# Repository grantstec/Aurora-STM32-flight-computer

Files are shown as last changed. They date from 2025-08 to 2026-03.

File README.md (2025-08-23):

# Aurora-STM32-flight-computer

## TO-DO
1. Finalize Parts List
2. Begin Schematic
3. Import OSH park pcb settings into KiCAD
4. Footprint demensions
5. Assemble footprint/layout
6. Traces
7. 3d Model?

## Resources
OSH park pcb setup link: https://github.com/grantstec/Aurora-STM32-flight-computer.git

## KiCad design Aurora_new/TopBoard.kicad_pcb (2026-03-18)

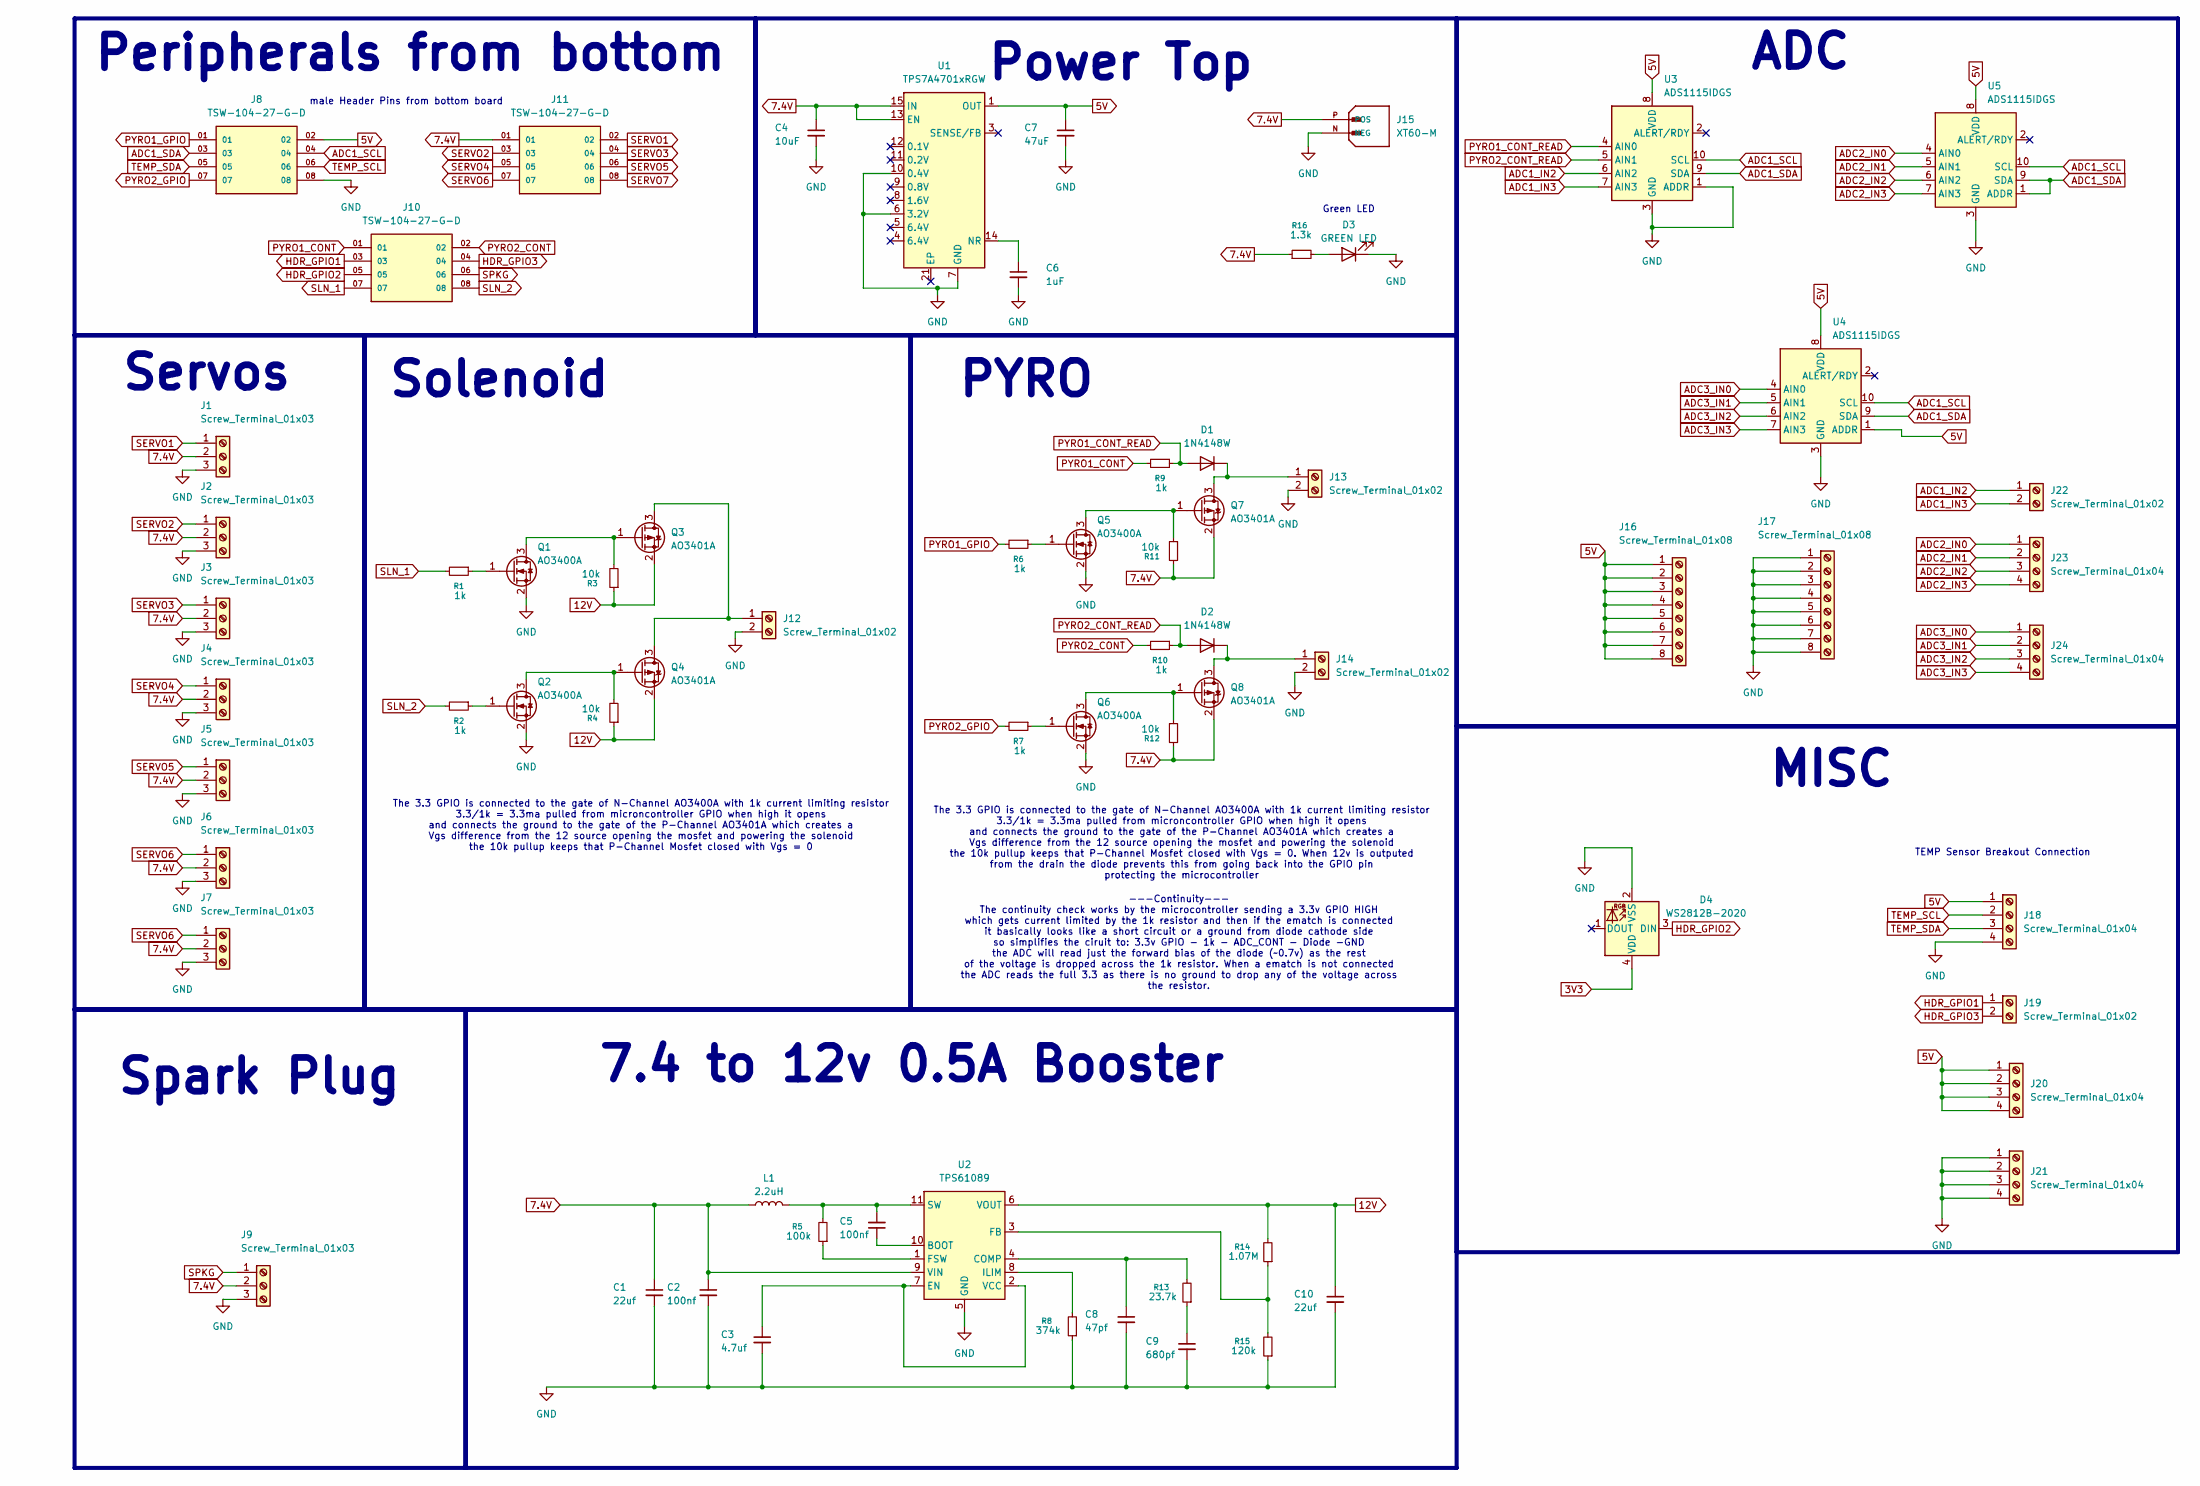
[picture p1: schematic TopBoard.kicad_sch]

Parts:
C1, C10: 22uf; C_0805_2012Metric
C2, C5: 100nf; C_0805_2012Metric
C3: 4.7uf; C_0805_2012Metric
C4: 10uF; C_0805_2012Metric
C6: 1uF; C_0805_2012Metric
C7: 47uF; C_0805_2012Metric
C8: 47pf; C_0805_2012Metric
C9: 680pf; C_0805_2012Metric
D1, D2: 1N4148W; D_SOD-123
D3: GREEN LED; LED_Cree-PLCC4_5x5mm_CW
D4: WS2812B-2020; LED_WS2812B-2020_PLCC4_2.0x2.0mm
J1, J2, J3, J4, J5, J6, J7, J9: Screw_Terminal_01x03; PHOENIX_1935174
J8, J10, J11: TSW-104-27-G-D; SAMTEC_TSW-104-27-G-D; PARTREV R
J12, J13, J14, J19, J22: Screw_Terminal_01x02; CONN_1729128_PXC
J15: XT60-M; AMASS_XT60-M; PARTREV V1.2
J16, J17: Screw_Terminal_01x08; CONN_1715789_PXC
J18, J20, J21, J23, J24: Screw_Terminal_01x04; CONN_1715747_PXC
L1: 2.2uH; L_0805_2012Metric
Q1, Q2, Q5, Q6: AO3400A; SOT-23
Q3, Q4, Q7, Q8: AO3401A; SOT-23
R1, R2, R6, R7, R9, R10: 1k; R_0805_2012Metric
R3, R4, R11, R12: 10k; R_0805_2012Metric
R5: 100k; R_0805_2012Metric
R8: 374k; R_0805_2012Metric
R13: 23.7k; R_0805_2012Metric
R14: 1.07M; R_0805_2012Metric
R15: 120k; R_0805_2012Metric
R16: 1.3k; R_0805_2012Metric
U1: TPS7A4701xRGW; Texas_RGW0020A_VQFN-20-1EP_5x5mm_P0.65mm_EP3.15x3.15mm
U2: TPS61089; Texas_VQFN-RNR0011A-11
U3, U4, U5: ADS1115IDGS; TSSOP-10_3x3mm_P0.5mm

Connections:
3V3: D4.4 (VDD)
5V: C7.1, J8.02, J16.1, J16.2, J16.3, J16.4, J16.5, J16.6, J16.7, J16.8, J18.1, J20.1, J20.2, J20.3, J20.4, U1.1 (OUT), U1.20 (OUT), U3.8 (VDD), U4.1 (ADDR), U4.8 (VDD), U5.8 (VDD)
7.4V: C1.1, C2.1, C4.1, J1.2, J2.2, J3.2, J4.2, J5.2, J6.2, J7.2, J9.2, J11.01, J15.P (POS), L1.1, Q7.2 (S), Q8.2 (S), R11.1, R12.1, R16.1, U1.13 (EN), U1.15 (IN), U1.16 (IN), U2.9 (VIN)
12V: C10.1, Q3.2 (S), Q4.2 (S), R3.1, R4.1, R14.2, U2.6 (VOUT)
ADC1_IN2: J22.1, U3.6 (AIN2)
ADC1_IN3: J22.2, U3.7 (AIN3)
ADC1_SCL: J8.04, U3.10 (SCL), U4.10 (SCL), U5.10 (SCL)
ADC1_SDA: J8.03, U3.9 (SDA), U4.9 (SDA), U5.1 (ADDR), U5.9 (SDA)
ADC2_IN0: J23.1, U5.4 (AIN0)
ADC2_IN1: J23.2, U5.5 (AIN1)
ADC2_IN2: J23.3, U5.6 (AIN2)
ADC2_IN3: J23.4, U5.7 (AIN3)
ADC3_IN0: J24.1, U4.4 (AIN0)
ADC3_IN1: J24.2, U4.5 (AIN1)
ADC3_IN2: J24.3, U4.6 (AIN2)
ADC3_IN3: J24.4, U4.7 (AIN3)
GND: C1.2, C2.2, C3.2, C4.2, C6.2, C7.2, C8.2, C9.2, C10.2, D3.1 (K), D4.2 (VSS), J1.3, J2.3, J3.3, J4.3, J5.3, J6.3, J7.3, J8.08, J9.3, J12.2, J13.2, J14.2, J15.N (NEG), J17.1, J17.2, J17.3, J17.4, J17.5, J17.6, J17.7, J17.8, J18.4, J21.1, J21.2, J21.3, J21.4, Q1.2 (S), Q2.2 (S), Q5.2 (S), Q6.2 (S), R8.1, R15.1, U1.6 (3.2V), U1.7 (GND), U1.10 (0.4V), U2.5 (GND), U3.1 (ADDR), U3.3 (GND), U4.3 (GND), U5.3 (GND)
HDR_GPIO1: J10.03, J19.1
HDR_GPIO2: D4.3 (DIN), J10.05
HDR_GPIO3: J10.04, J19.2
unnamed: C9.1, R13.1
unnamed: D1.1 (K), J13.1, Q7.3 (D)
unnamed: D2.1 (K), J14.1, Q8.3 (D)
unnamed: D3.2 (A), R16.2
unnamed: J12.1, Q3.3 (D), Q4.3 (D)
unnamed: Q1.3 (D), Q3.1 (G), R3.2
unnamed: Q1.1 (G), R1.1
unnamed: Q2.3 (D), Q4.1 (G), R4.2
unnamed: Q2.1 (G), R2.1
unnamed: Q5.3 (D), Q7.1 (G), R11.2
unnamed: Q5.1 (G), R6.1
unnamed: Q6.3 (D), Q8.1 (G), R12.2
unnamed: Q6.1 (G), R7.1
unnamed: C6.1, U1.14 (NR)
unnamed: C5.1, U2.10 (BOOT)
unnamed: C8.1, R13.2, U2.4 (COMP)
unnamed: C3.1, U2.2 (VCC), U2.7 (EN)
unnamed: R14.1, R15.2, U2.3 (FB)
unnamed: R5.1, U2.1 (FSW)
unnamed: R8.2, U2.8 (ILIM)
unnamed: C5.2, L1.2, R5.2, U2.11 (SW)
PYRO1_CONT: J10.01, R9.2
PYRO1_CONT_READ: D1.2 (A), R9.1, U3.4 (AIN0)
PYRO1_GPIO: J8.01, R6.2
PYRO2_CONT: J10.02, R10.2
PYRO2_CONT_READ: D2.2 (A), R10.1, U3.5 (AIN1)
PYRO2_GPIO: J8.07, R7.2
SERVO1: J1.1, J11.02
SERVO2: J2.1, J11.03
SERVO3: J3.1, J11.04
SERVO4: J4.1, J11.05
SERVO5: J5.1, J11.06
SERVO6: J6.1, J7.1, J11.07
SERVO7: J11.08
SLN_1: J10.07, R1.2
SLN_2: J10.08, R2.2
SPKG: J9.1, J10.06
TEMP_SCL: J8.06, J18.2
TEMP_SDA: J8.05, J18.3

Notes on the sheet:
ADC
Power Top
MISC
male Header Pins from bottom board
The 3.3 GPIO is connected to the gate of N-Channel AO3400A with 1k current limiting resistor 3.3/1k = 3.3ma pulled from microncontroller GPIO when high it opens and connects the ground to the gate of the P-Channel AO3401A which creates a Vgs difference from the 12 source opening the mosfet and powe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
Peripherals from bottom
PYRO
TEMP Sensor Breakout Connection
Spark Plug
The 3.3 GPIO is connected to the gate of N-Channel AO3400A with 1k current limiting resistor 3.3/1k = 3.3ma pulled from microncontroller GPIO when high it opens and connects the ground to the gate of the P-Channel AO3401A which creates a Vgs difference from the 12 source opening the mosfet and powe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
---Continuity--- The continuity check works by the microcontroller sending a 3.3v GPIO HIGH which gets current limited by the 1k resistor and then if the ematch is connected it basically looks like a short circuit or a ground from diode cathode side so simplifies the ciruit to: 3.3v GPIO - 1k - ADC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
Green LED
7.4 to 12v 0.5A Booster
Solenoid
Servos

Board: 2 copper layers, 68 parts (0 on the bottom side), 57 nets, no tracks yet.

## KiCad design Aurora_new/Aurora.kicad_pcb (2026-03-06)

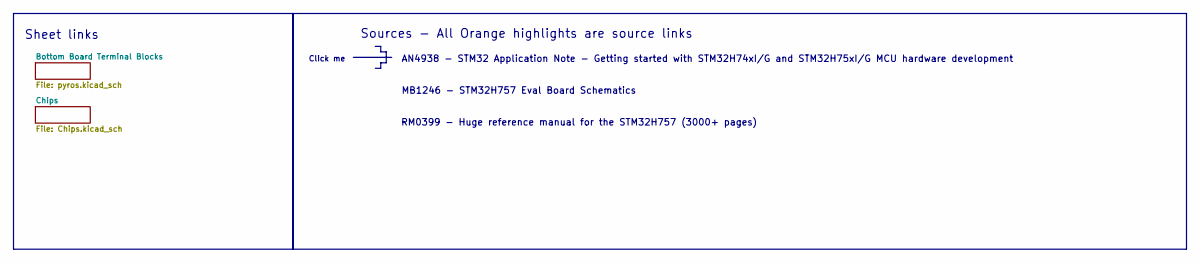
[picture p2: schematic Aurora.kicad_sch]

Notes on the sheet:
RM0399 - Huge reference manual for the STM32H757 (3000+ pages)
AN4938 - STM32 Application Note - Getting started with STM32H74xI/G and STM32H75xI/G MCU hardware development
MB1246 - STM32H757 Eval Board Schematics
Sheet links
Sources - All Orange highlights are source links
Click me

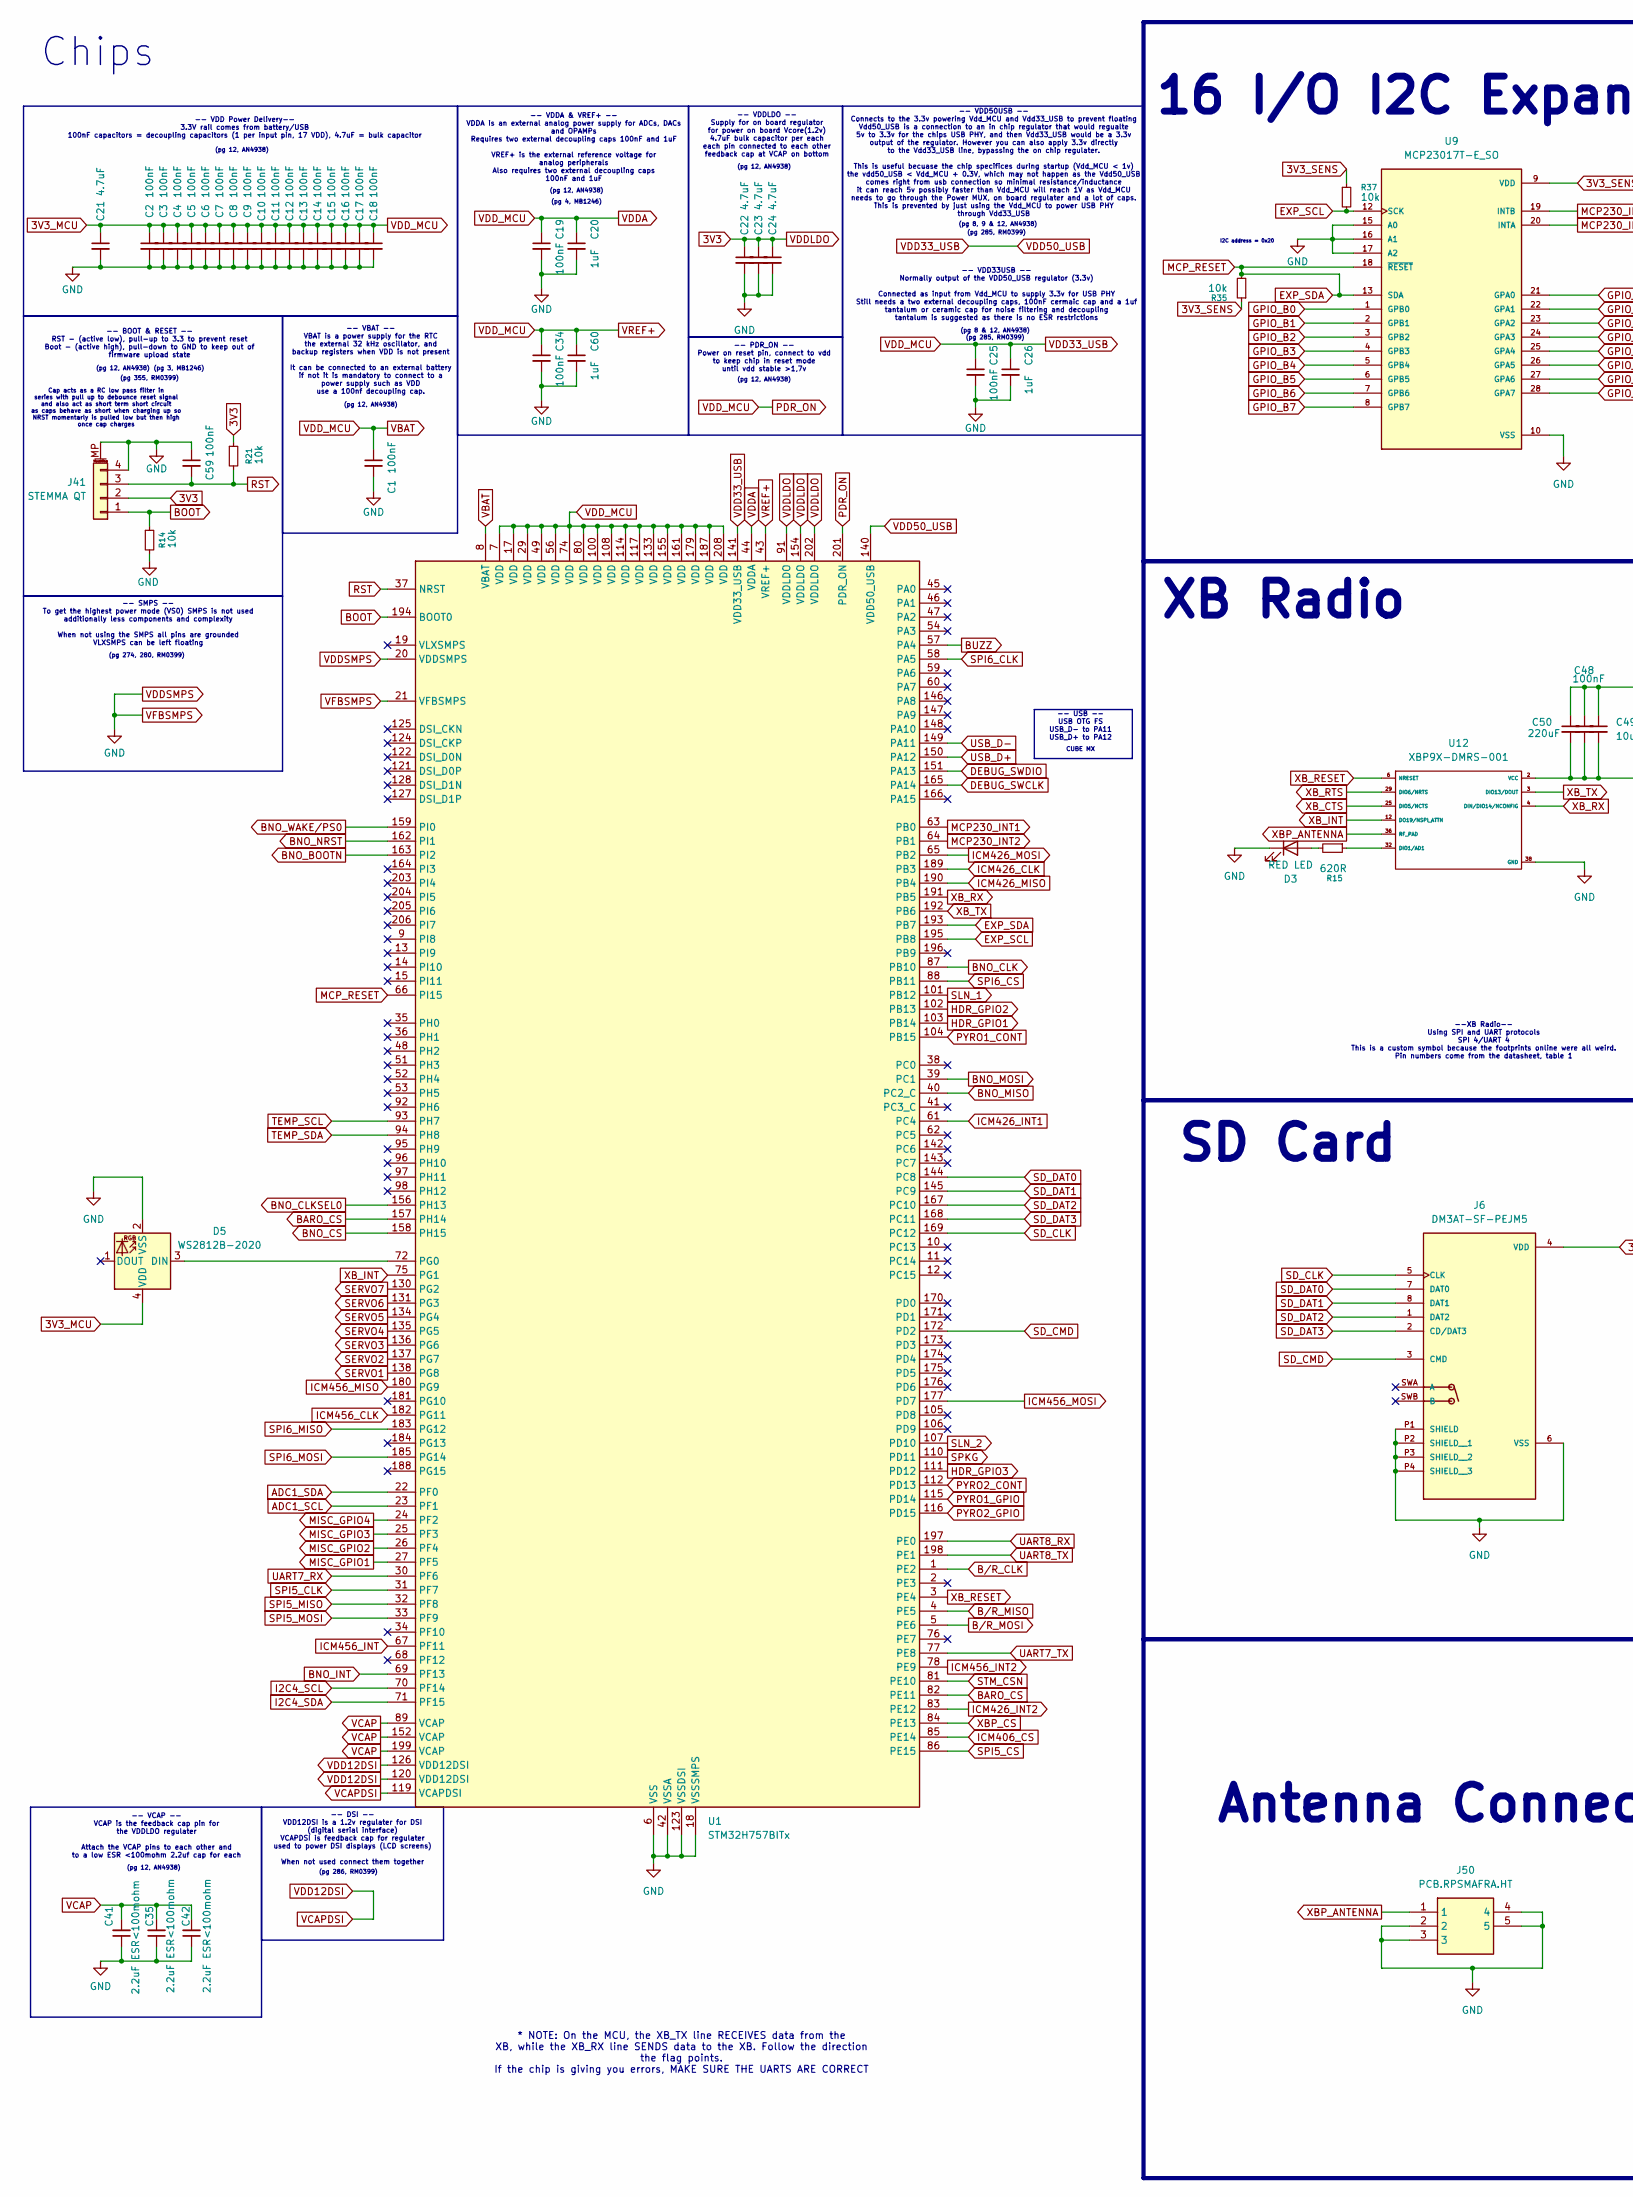
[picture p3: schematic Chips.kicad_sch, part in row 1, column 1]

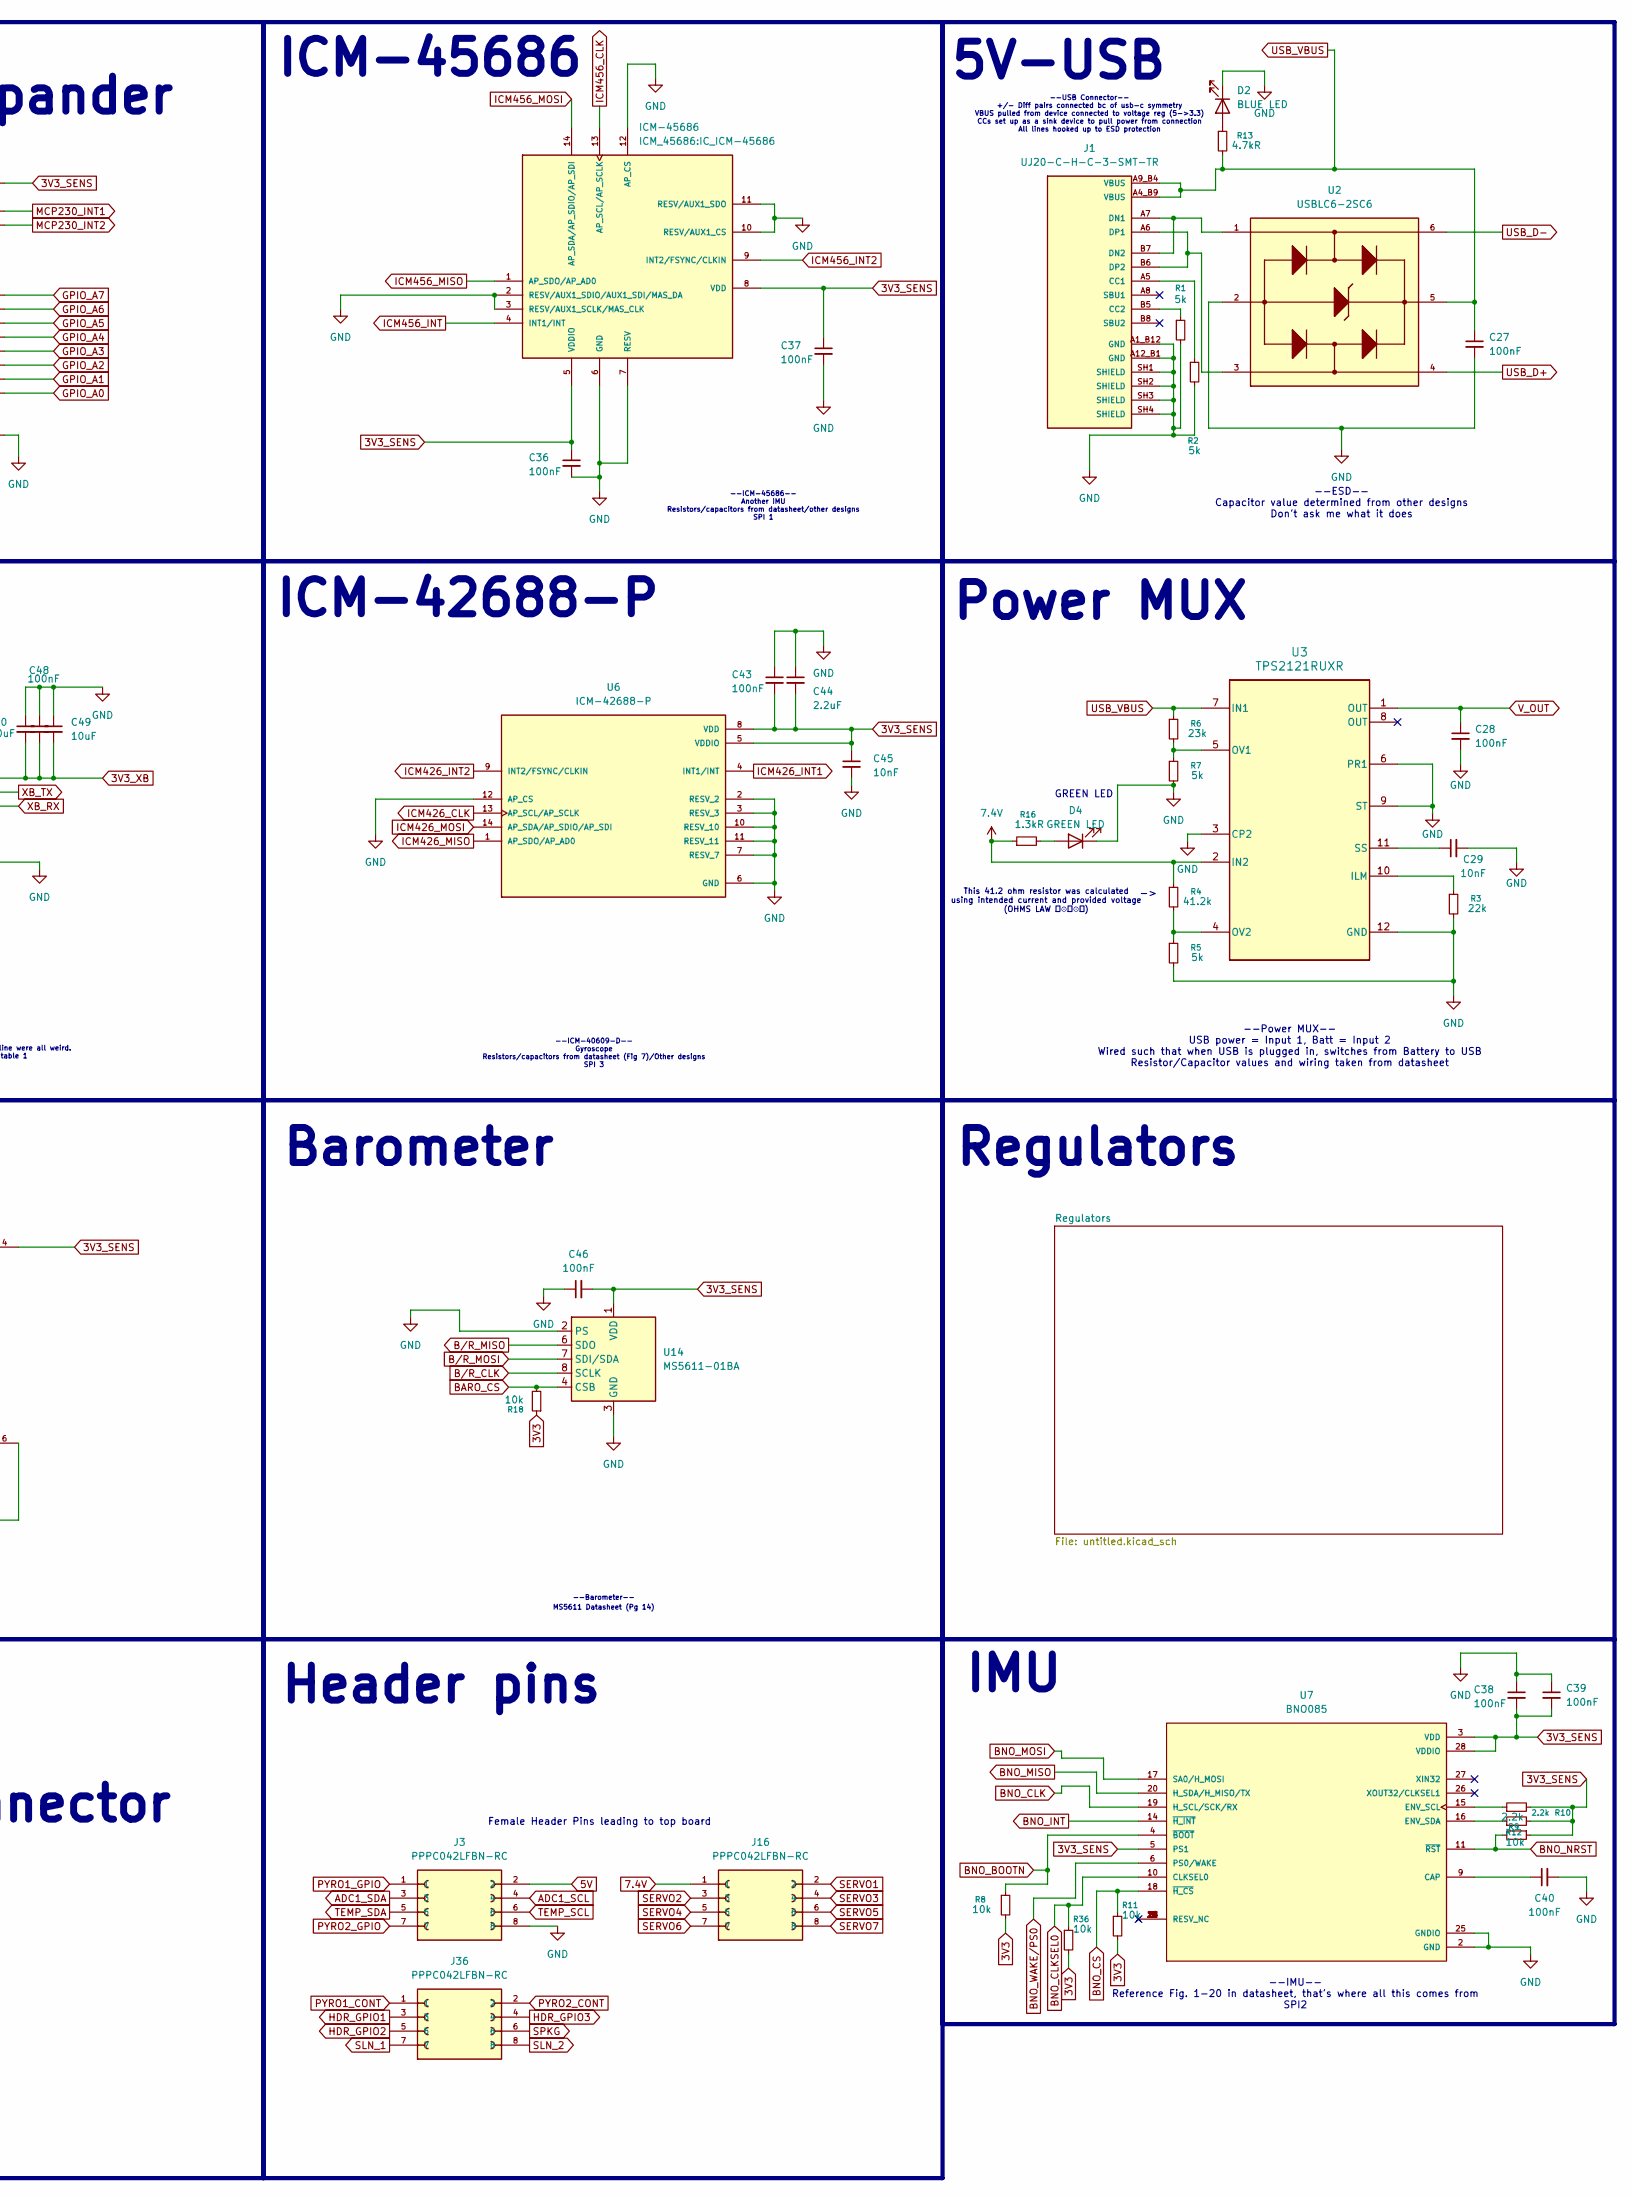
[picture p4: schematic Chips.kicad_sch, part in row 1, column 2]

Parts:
C1, C2, C3, C4, C5, C6, C7, C8, C9, C10, C11, C12, C13, C14, C15, C16, C17, C18, C19, C25, C27, C28, C34, C36, C37, C38, C39, C40, C43, C46, C48, C59: 100nF; C_0805_2012Metric
C20, C26, C60: 1uF; C_0805_2012Metric
C21, C22, C23, C24: 4.7uF; C_0805_2012Metric
C29, C45: 10nF; C_0805_2012Metric
C35, C41, C42: 2.2uF ESR<100mohm; C_0805_2012Metric
C44: 2.2uF; C_0805_2012Metric
C49: 10uF; C_0805_2012Metric
C50: 220uF; C_1206_3216Metric
D2: BLUE LED; LED_Cree-PLCC4_5x5mm_CW
D3: RED LED; LED_Cree-PLCC4_5x5mm_CW
D4: GREEN LED; LED_Cree-PLCC4_5x5mm_CW
D5: WS2812B-2020; LED_WS2812B-2020_PLCC4_2.0x2.0mm
J1: UJ20-C-H-C-3-SMT-TR; CUI_UJ20-C-H-C-3-SMT-TR; PARTREV 1.0
J3, J16, J36: PPPC042LFBN-RC; SULLINS_PPPC042LFBN-RC; PARTREV L
J6: DM3AT-SF-PEJM5; HRS_DM3AT-SF-PEJM5; PARTREV 20200913
J41: STEMMA QT; JST_SH_SM04B-SRSS-TB_1x04-1MP_P1.00mm_Horizontal
J50: PCB.RPSMAFRA.HT; PCBRPSMAFRAHT; Mouser Part Number 960-PCB.RPSMAFRA.HT
R1, R2, R5, R7: 5k; R_0805_2012Metric
R3: 22k; R_0805_2012Metric
R4: 41.2k; R_0805_2012Metric
R6: 23k; R_0805_2012Metric
R8, R11, R12, R14, R18, R21, R35, R36, R37: 10k; R_0805_2012Metric
R9, R10: 2.2k; R_0805_2012Metric
R13: 4.7kR; R_0805_2012Metric
R15: 620R; R_0805_2012Metric
R16: 1.3kR; R_0805_2012Metric
U1: STM32H757BITx; LQFP-208_28x28mm_P0.5mm
U2: USBLC6-2SC6; SOT95P280X145-6N
U3: TPS2121RUXR; RUX0012A
U5: ICM-45686; IC_ICM-45686; PARTREV 0.2
U6: ICM-42688-P; PQFN50P300X250X97-14N; PARTREV 1.2
U7: BNO085; IC_BNO085; PARTREV v1.17
U9: MCP23017T-E_SO; SOIC127P1030X265-28N
U12: XBP9X-DMRS-001; XCVR_XBP9X-DMUS-021
U14: MS5611-01BA; LGA-8_3x5mm_P1.25mm

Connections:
3V3: C22.1, C23.1, C24.1, J41.2, R8.2, R11.2, R18.1, R21.1, R36.2, U1.91 (VDDLDO), U1.154 (VDDLDO), U1.202 (VDDLDO); also elsewhere on the board
3V3_MCU: C1.1, C2.1, C3.1, C4.1, C5.1, C6.1, C7.1, C8.1, C9.1, C10.1, C11.1, C12.1, C13.1, C14.1, C15.1, C16.1, C17.1, C18.1, C19.1, C20.1, C21.1, C25.1, C26.1, C34.1, C60.1, D5.4 (VDD), U1.7 (VDD), U1.8 (VBAT), U1.17 (VDD), U1.29 (VDD), U1.43 (VREF+), U1.44 (VDDA), U1.49 (VDD), U1.56 (VDD), U1.74 (VDD), U1.80 (VDD), U1.100 (VDD), U1.108 (VDD), U1.114 (VDD), U1.117 (VDD), U1.133 (VDD), U1.140 (VDD50_USB), U1.141 (VDD33_USB), U1.155 (VDD), U1.161 (VDD), U1.179 (VDD), U1.187 (VDD), U1.201 (PDR_ON), U1.208 (VDD); also elsewhere on the board
3V3_SENS: C36.1, C37.1, C38.2, C39.2, C43.2, C44.2, C45.1, C46.2, J6.4 (VDD), R9.2, R10.2, R12.1, R35.1, R37.1, U5.5 (VDDIO), U5.8 (VDD), U6.5 (VDDIO), U6.8 (VDD), U7.3 (VDD), U7.5 (PS1), U7.28 (VDDIO), U9.9 (VDD), U14.1 (VDD); also elsewhere on the board
3V3_XB: C48.2, C49.2, C50.2, U12.2 (VCC); also elsewhere on the board
5V: J3.2
7.4V: J16.1, R4.1, R16.1, U3.2 (IN2)
ADC1_SCL: J3.4, U1.23 (PF1)
ADC1_SDA: J3.3, U1.22 (PF0)
BARO_CS: R18.2, U1.82 (PE11), U1.157 (PH14), U14.4 (CSB), U14.5 (CSB)
BNO_BOOTN: R8.1, U1.163 (PI2), U7.4 (~BOOT)
BNO_CLK: U1.87 (PB10), U7.19 (H_SCL/SCK/RX)
BNO_CLKSEL0: R36.1, U1.156 (PH13), U7.10 (CLKSEL0)
BNO_CS: R11.1, U1.158 (PH15), U7.18 (~H_CS)
BNO_INT: U1.69 (PF13), U7.14 (~H_INT)
BNO_MISO: U1.40 (PC2_C), U7.20 (H_SDA/H_MISO/TX)
BNO_MOSI: U1.39 (PC1), U7.17 (SA0/H_MOSI)
BNO_NRST: R12.2, U1.162 (PI1), U7.11 (~RST)
BNO_WAKE/PS0: U1.159 (PI0), U7.6 (PS0/WAKE)
BOOT: J41.1, R14.1, U1.194 (BOOT0)
BUZZ: U1.57 (PA4); also elsewhere on the board
B/R_CLK: U1.1 (PE2), U14.8 (SCLK)
B/R_MISO: U1.4 (PE5), U14.6 (SDO)
B/R_MOSI: U1.5 (PE6), U14.7 (SDI/SDA)
DEBUG_SWCLK: U1.165 (PA14); also elsewhere on the board
DEBUG_SWDIO: U1.151 (PA13); also elsewhere on the board
EXP_SCL: R37.2, U1.195 (PB8), U9.12 (SCK)
EXP_SDA: R35.2, U1.66 (PI15), U1.193 (PB7), U9.13 (SDA), U9.18 (~RESET)
GPIO_A0: U9.28 (GPA7); also elsewhere on the board
GPIO_A1: U9.27 (GPA6); also elsewhere on the board
GPIO_A2: U9.26 (GPA5); also elsewhere on the board
GPIO_A3: U9.25 (GPA4); also elsewhere on the board
GPIO_A4: U9.24 (GPA3); also elsewhere on the board
GPIO_A5: U9.23 (GPA2); also elsewhere on the board
GPIO_A6: U9.22 (GPA1); also elsewhere on the board
GPIO_A7: U9.21 (GPA0); also elsewhere on the board
GPIO_B0: U9.1 (GPB0); also elsewhere on the board
GPIO_B1: U9.2 (GPB1); also elsewhere on the board
GPIO_B2: U9.3 (GPB2); also elsewhere on the board
GPIO_B3: U9.4 (GPB3); also elsewhere on the board
GPIO_B4: U9.5 (GPB4); also elsewhere on the board
GPIO_B5: U9.6 (GPB5); also elsewhere on the board
GPIO_B6: U9.7 (GPB6); also elsewhere on the board
GPIO_B7: U9.8 (GPB7); also elsewhere on the board
HDR_GPIO1: J36.3, U1.103 (PB14)
HDR_GPIO2: J36.5, U1.102 (PB13)
HDR_GPIO3: J36.4, U1.111 (PD12)
I2C4_SCL: U1.70 (PF14); also elsewhere on the board
I2C4_SDA: U1.71 (PF15); also elsewhere on the board
ICM406_CS: U1.85 (PE14)
ICM426_CLK: U1.189 (PB3), U6.13 (AP_SCL/AP_SCLK)
ICM426_INT1: U1.61 (PC4), U6.4 (INT1/INT)
ICM426_INT2: U1.83 (PE12), U6.9 (INT2/FSYNC/CLKIN)
ICM426_MISO: U1.190 (PB4), U6.1 (AP_SDO/AP_AD0)
ICM426_MOSI: U1.65 (PB2), U6.14 (AP_SDA/AP_SDIO/AP_SDI)
ICM456_CLK: U1.182 (PG11), U5.13 (AP_SCL/AP_SCLK)
ICM456_INT: U1.67 (PF11), U5.4 (INT1/INT)
ICM456_INT2: U1.78 (PE9), U5.9 (INT2/FSYNC/CLKIN)
ICM456_MISO: U1.180 (PG9), U5.1 (AP_SDO/AP_AD0)
ICM456_MOSI: U1.177 (PD7), U5.14 (AP_SDA/AP_SDIO/AP_SDI)
MCP230_INT1: U1.63 (PB0), U9.19 (INTB)
MCP230_INT2: U1.64 (PB1), U9.20 (INTA)
MISC_GPIO1: U1.27 (PF5); also elsewhere on the board
MISC_GPIO2: U1.26 (PF4); also elsewhere on the board
MISC_GPIO3: U1.25 (PF3); also elsewhere on the board
MISC_GPIO4: U1.24 (PF2); also elsewhere on the board
unnamed: D2.2 (A), R13.1
unnamed: D3.2 (A), R15.2
unnamed: D4.2 (A), R16.2
unnamed: D5.3 (DIN), U1.72 (PG0)
unnamed: J1.A5 (CC1), R2.1
unnamed: J1.B5 (CC2), R1.1
unnamed: J1.A7 (DN1), J1.B7 (DN2), U2.1
unnamed: J1.A6 (DP1), J1.B6 (DP2), U2.3
unnamed: R3.1, U3.10 (ILM)
unnamed: R6.2, R7.1, U3.5 (OV1)
unnamed: R4.2, R5.1, U3.4 (OV2)
unnamed: C29.1, U3.11 (SS)
unnamed: C40.1, U7.9 (CAP)
unnamed: R10.1, U7.15 (ENV_SCL)
unnamed: R9.1, U7.16 (ENV_SDA)
unnamed: R15.1, U12.32 (DIO1/AD1)
PYRO1_CONT: J36.1, U1.104 (PB15)
PYRO1_GPIO: J3.1, U1.115 (PD14)
PYRO2_CONT: J36.2, U1.112 (PD13)
PYRO2_GPIO: J3.7, U1.116 (PD15)
RST: C59.2, J41.3, R21.2, U1.37 (NRST)
SD_CLK: J6.5 (CLK), U1.169 (PC12)
SD_CMD: J6.3 (CMD), U1.172 (PD2)
SD_DAT0: J6.7 (DAT0), U1.144 (PC8)
SD_DAT1: J6.8 (DAT1), U1.145 (PC9)
SD_DAT2: J6.1 (DAT2), U1.167 (PC10)
SD_DAT3: J6.2 (CD/DAT3), U1.168 (PC11)
SERVO1: J16.2, U1.138 (PG8)
SERVO2: J16.3, U1.137 (PG7)
SERVO3: J16.4, U1.136 (PG6)
SERVO4: J16.5, U1.135 (PG5)
SERVO5: J16.6, U1.134 (PG4)
SERVO6: J16.7, U1.131 (PG3)
SERVO7: J16.8, U1.130 (PG2)
SLN_1: J36.7, U1.101 (PB12)
SLN_2: J36.8, U1.107 (PD10)
SPI5_CLK: U1.31 (PF7); also elsewhere on the board
SPI5_CS: U1.86 (PE15); also elsewhere on the board
SPI5_MISO: U1.32 (PF8); also elsewhere on the board
SPI5_MOSI: U1.33 (PF9); also elsewhere on the board
SPI6_CLK: U1.58 (PA5); also elsewhere on the board
SPI6_CS: U1.88 (PB11); also elsewhere on the board
SPI6_MISO: U1.183 (PG12); also elsewhere on the board
SPI6_MOSI: U1.185 (PG14); also elsewhere on the board
SPKG: J36.6, U1.110 (PD11)
STM_CSN: U1.81 (PE10)
TEMP_SCL: J3.6, U1.93 (PH7)
TEMP_SDA: J3.5, U1.94 (PH8)
UART7_RX: U1.30 (PF6); also elsewhere on the board
UART7_TX: U1.77 (PE8); also elsewhere on the board
UART8_RX: U1.197 (PE0); also elsewhere on the board
UART8_TX: U1.198 (PE1); also elsewhere on the board
USB_D+: U1.150 (PA12), U2.4
USB_D-: U1.149 (PA11), U2.6
USB_VBUS: C27.1, J1.A4_B9 (VBUS), J1.A9_B4 (VBUS), R6.1, R13.2, U2.5, U3.7 (IN1); also elsewhere on the board
VCAP: C35.2, C41.2, C42.2, U1.89 (VCAP), U1.152 (VCAP), U1.199 (VCAP)
VCAPDSI: U1.119 (VCAPDSI), U1.120 (VDD12DSI), U1.126 (VDD12DSI)
VDDSMPS: C1.2, C2.2, C3.2, C4.2, C5.2, C6.2, C7.2, C8.2, C9.2, C10.2, C11.2, C12.2, C13.2, C14.2, C15.2, C16.2, C17.2, C18.2, C19.2, C20.2, C21.2, C22.2, C23.2, C24.2, C25.2, C26.2, C27.2, C28.2, C29.2, C34.2, C35.1, C36.2, C37.2, C38.1, C39.1, C40.2, C41.1, C42.1, C43.1, C44.1, C45.2, C46.1, C48.1, C49.1, C50.1, C59.1, C60.2, D2.1 (K), D3.1 (K), D4.1 (K), D5.2 (VSS), J1.A1_B12 (GND), J1.A12_B1 (GND), J1.SH1 (SHIELD), J1.SH2 (SHIELD), J1.SH3 (SHIELD), J1.SH4 (SHIELD), J3.8, J6.6 (VSS), J6.P1 (SHIELD), J6.P2 (SHIELD__1), J6.P3 (SHIELD__2), J6.P4 (SHIELD__3), J41.4, J41.MP (MountPin), J50.2, J50.3, J50.4, J50.5, R1.2, R2.2, R3.2, R5.2, R7.2, R14.2, U1.6 (VSS), U1.16 (VSS), U1.18 (VSSSMPS), U1.20 (VDDSMPS), U1.21 (VFBSMPS), U1.28 (VSS), U1.42 (VSSA), U1.50 (VSS), U1.55 (VSS), U1.73 (VSS), U1.79 (VSS), U1.90 (VSS), U1.99 (VSS), U1.109 (VSS), U1.113 (VSS), U1.118 (VSS), U1.123 (VSSDSI), U1.129 (VSSDSI), U1.132 (VSS), U1.139 (VSS), U1.153 (VSS), U1.160 (VSS), U1.178 (VSS), U1.186 (VSS), U1.200 (VSS), U1.207 (VSS), U2.2, U3.3 (CP2), U3.6 (PR1), U3.9 (ST), U3.12 (GND), U5.2 (RESV/AUX1_SDIO/AUX1_SDI/MAS_DA), U5.3 (RESV/AUX1_SCLK/MAS_CLK), U5.6 (GND), U5.7 (RESV), U5.10 (RESV/AUX1_CS), U5.11 (RESV/AUX1_SDO), U5.12 (AP_CS), U6.2 (RESV_2), U6.3 (RESV_3), U6.6 (GND), U6.7 (RESV_7), U6.10 (RESV_10), U6.11 (RESV_11), U6.12 (AP_CS), U7.2 (GND), U7.25 (GNDIO), U9.10 (VSS), U9.15 (A0), U9.16 (A1), U9.17 (A2), U12.38 (GND), U14.2 (PS), U14.3 (GND); also elsewhere on the board
V_OUT: C28.1, U3.1 (OUT); also elsewhere on the board
XBP_ANTENNA: J50.1, U12.36 (RF_PAD)
XBP_CS: U1.84 (PE13)
XB_CTS: U12.25 (DIO5/NCTS); also elsewhere on the board
XB_INT: U1.75 (PG1), U12.12 (DO19/NSPI_ATTN)
XB_RESET: U1.3 (PE4), U12.6 (NRESET)
XB_RTS: U12.29 (DIO6/NRTS); also elsewhere on the board
XB_RX: U1.191 (PB5), U12.4 (DIN/DIO14/NCONFIG); also elsewhere on the board
XB_TX: U1.192 (PB6), U12.3 (DIO13/DOUT); also elsewhere on the board

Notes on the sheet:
(pg 12, AN4938)
(pg 4, MB1246)
XB Radio
--XB Radio-- Using SPI and UART protocols SPI 4/UART 4 This is a custom symbol because the footprints online were all weird. Pin numbers come from the datasheet, table 1
-- VDDA & VREF+ -- VDDA is an external analog power supply for ADCs, DACs and OPAMPs Requires two external decoupling caps 100nF and 1uF VREF+ is the external reference voltage for analog peripherals Also requires two external decoupling caps 100nF and 1uF
-- PDR_ON -- Power on reset pin, connect to vdd to keep chip in reset mode until vdd stable >1,7v
--Power MUX-- USB power = Input 1, Batt = Input 2 Wired such that when USB is plugged in, switches from Battery to USB Resistor/Capacitor values and wiring taken from datasheet
-- VDD50USB -- Connects to the 3.3v powering Vdd_MCU and Vdd33_USB to prevent floating Vdd50_USB is a connection to an in chip regulator that would regualte 5v to 3.3v for the chips USB PHY, and then Vdd33_USB would be a 3.3v output of the regulator. However you can also apply 3.3v directly to the 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
ICM-42688-P
Barometer
--Barometer--
(pg 8, 9 & 12, AN4938)
(pg 285, RM0399)
GREEN LED
Header pins
--IMU-- Reference Fig. 1-20 in datasheet, that's where all this comes from SPI2
* NOTE: On the MCU, the XB_TX line RECEIVES data from the XB, while the XB_RX line SENDS data to the XB. Follow the direction the flag points. If the chip is giving you errors, MAKE SURE THE UARTS ARE CORRECT
-- VDD Power Delivery-- 3.3V rail comes from battery/USB 100nF capacitors = decoupling capacitors (1 per input pin, 17 VDD), 4.7uF = bulk capacitor
Power MUX
-- VBAT -- VBAT is a power supply for the RTC the external 32 kHz oscillator, and backup registers when VDD is not present It can be connected to an external battery if not it is mandatory to connect to a power supply such as VDD use a 100nf decoupling cap.
CUBE MX
(pg 12, AN4938)
--ESD-- Capacitor value determined from other designs Don't ask me what it does
(pg 355, RM0399)
(pg 3, MB1246)
Female Header Pins leading to top board
--ICM-40609-D-- Gyroscope Resistors/capacitors from datasheet (Fig 7)/Other designs SPI 3
MS5611 Datasheet (Pg 14)
--USB Connector-- +/- Diff pairs connected bc of usb-c symmetry VBUS pulled from device connected to voltage reg (5->3.3) CCs set up as a sink device to pull power from connection All lines hooked up to ESD protection
Antenna Connector
Regulators
-- VCAP -- VCAP is the feedback cap pin for the VDDLDO regulater Attach the VCAP pins to each other and to a low ESR <100mohm 2.2uf cap for each
This 41.2 ohm resistor was calculated using intended current and provided voltage (OHMS LAW （⊙ｏ⊙）)
I2C address = 0x20
IMU
(pg 274, 280, RM0399)
(pg 286, RM0399)
-- VDDLDO -- Supply for on board regulator for power on board Vcore(1.2v) 4.7uF bulk capacitor per each each pin connected to each other feedback cap at VCAP on bottom
(pg 8 & 12, AN4938)
-- VDD33USB -- Normally output of the VDD50_USB regulator (3.3v) Connected as input from Vdd_MCU to supply 3.3v for USB PHY Still needs a two external decoupling caps, 100nF cermaic cap and a 1uf tantalum or ceramic cap for noise filtering and decoupling tantalum is suggested as there is no ESR res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

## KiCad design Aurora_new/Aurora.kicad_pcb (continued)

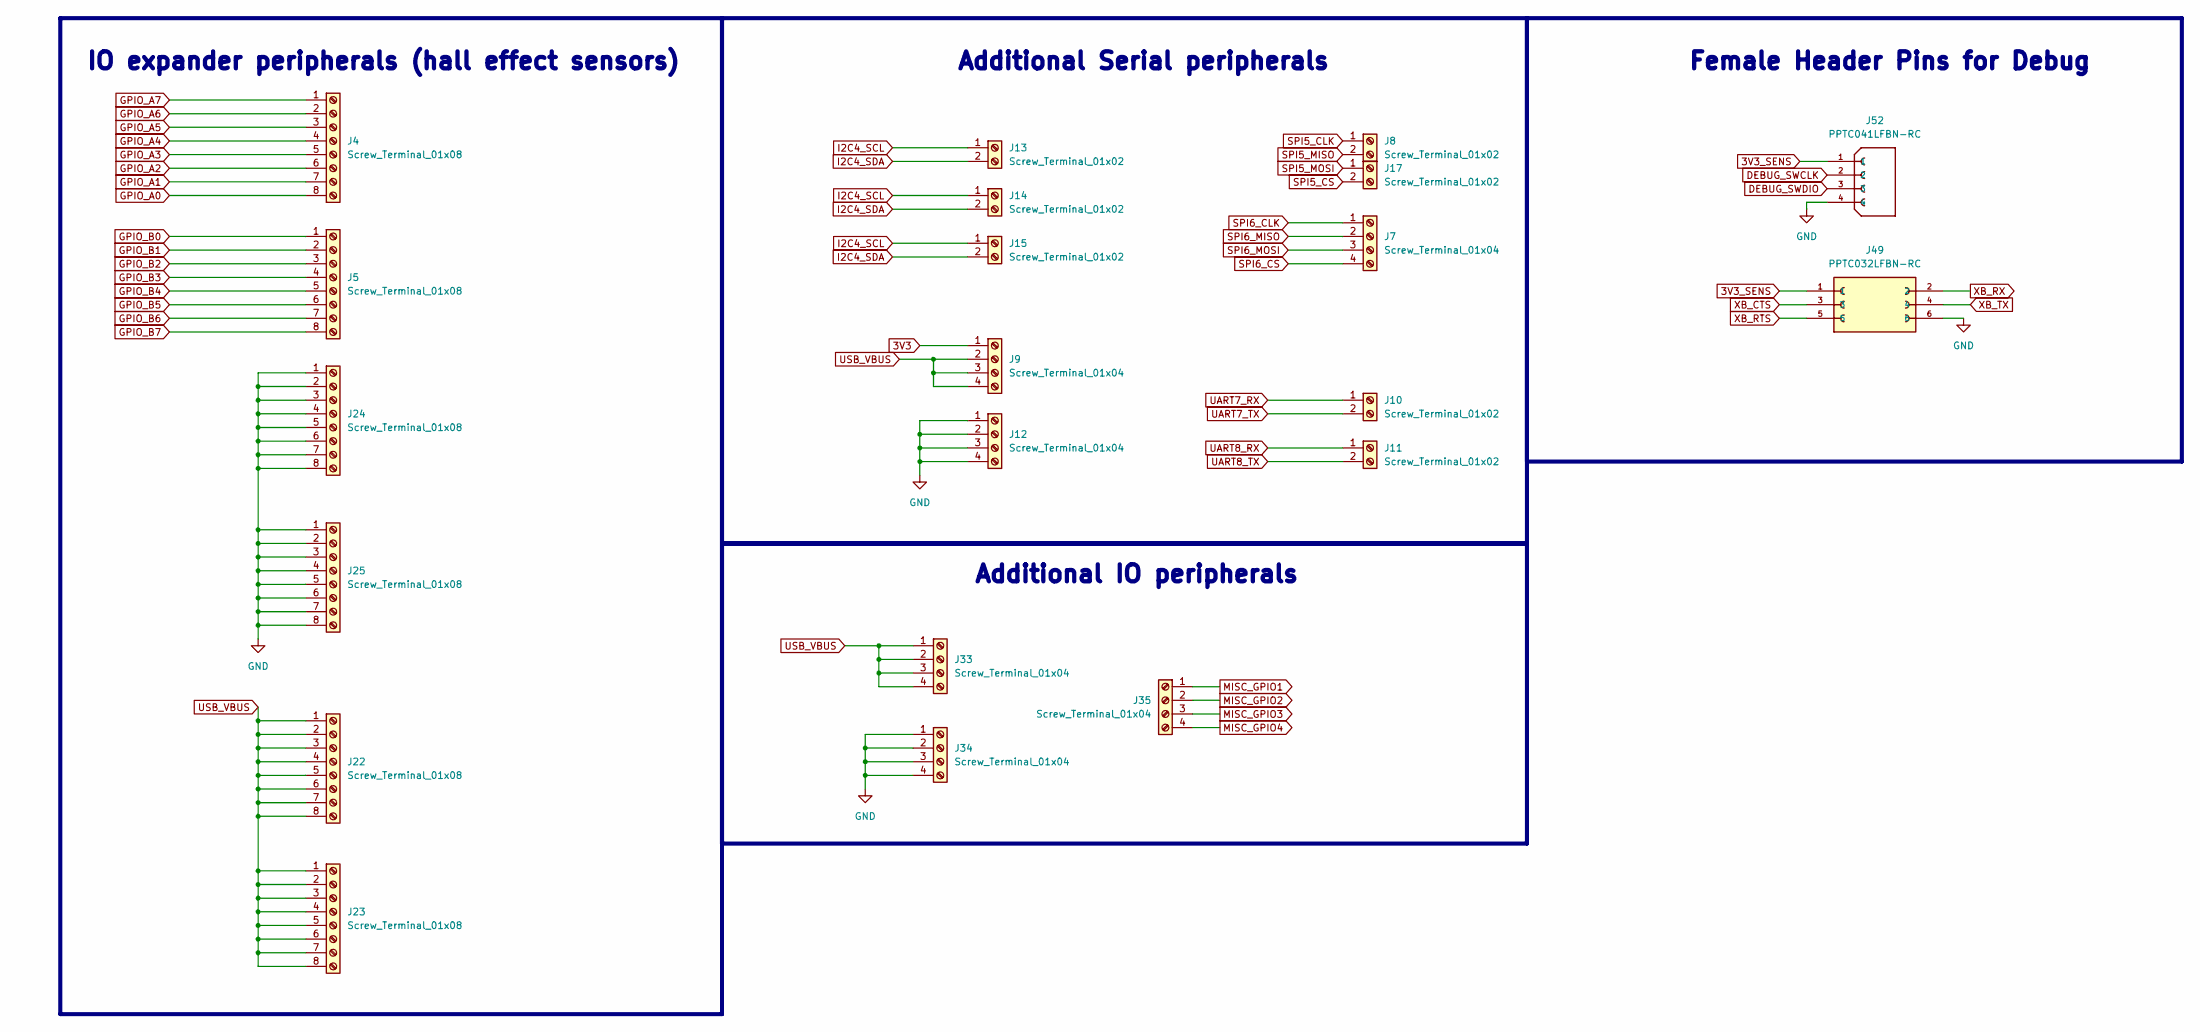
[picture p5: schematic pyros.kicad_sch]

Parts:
J4, J5, J22, J23, J24, J25: Screw_Terminal_01x08; PHOENIX_1725711
J7, J9, J12, J33, J34, J35: Screw_Terminal_01x04; PHOENIX_1725672
J8, J10, J11, J13, J14, J15, J17: Screw_Terminal_01x02; PHOENIX_1725656
J49: PPTC032LFBN-RC; PinSocket_2x03_P1.00mm_Vertical_SMD; PARTREV L
J52: PPTC041LFBN-RC; PinSocket_1x04_P2.54mm_Vertical; PARTREV J - 04/15/2015

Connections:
3V3: J9.1; also elsewhere on the board
3V3_SENS: J49.1, J52.1; also elsewhere on the board
DEBUG_SWCLK: J52.2; also elsewhere on the board
DEBUG_SWDIO: J52.3; also elsewhere on the board
GPIO_A0: J4.8; also elsewhere on the board
GPIO_A1: J4.7; also elsewhere on the board
GPIO_A2: J4.6; also elsewhere on the board
GPIO_A3: J4.5; also elsewhere on the board
GPIO_A4: J4.4; also elsewhere on the board
GPIO_A5: J4.3; also elsewhere on the board
GPIO_A6: J4.2; also elsewhere on the board
GPIO_A7: J4.1; also elsewhere on the board
GPIO_B0: J5.1; also elsewhere on the board
GPIO_B1: J5.2; also elsewhere on the board
GPIO_B2: J5.3; also elsewhere on the board
GPIO_B3: J5.4; also elsewhere on the board
GPIO_B4: J5.5; also elsewhere on the board
GPIO_B5: J5.6; also elsewhere on the board
GPIO_B6: J5.7; also elsewhere on the board
GPIO_B7: J5.8; also elsewhere on the board
I2C4_SCL: J13.1, J14.1, J15.1; also elsewhere on the board
I2C4_SDA: J13.2, J14.2, J15.2; also elsewhere on the board
MISC_GPIO1: J35.1; also elsewhere on the board
MISC_GPIO2: J35.2; also elsewhere on the board
MISC_GPIO3: J35.3; also elsewhere on the board
MISC_GPIO4: J35.4; also elsewhere on the board
SPI6_CLK: J7.1; also elsewhere on the board
SPI6_CS: J7.4; also elsewhere on the board
SPI6_MISO: J7.2; also elsewhere on the board
SPI6_MOSI: J7.3; also elsewhere on the board
UART7_RX: J10.1; also elsewhere on the board
UART7_TX: J10.2; also elsewhere on the board
UART8_RX: J11.1; also elsewhere on the board
UART8_TX: J11.2; also elsewhere on the board
USB_VBUS: J9.2, J9.3, J9.4, J22.1, J22.2, J22.3, J22.4, J22.5, J22.6, J22.7, J22.8, J23.1, J23.2, J23.3, J23.4, J23.5, J23.6, J23.7, J23.8, J33.1, J33.2, J33.3, J33.4; also elsewhere on the board
VDDSMPS: J12.1, J12.2, J12.3, J12.4, J24.1, J24.2, J24.3, J24.4, J24.5, J24.6, J24.7, J24.8, J25.1, J25.2, J25.3, J25.4, J25.5, J25.6, J25.7, J25.8, J34.1, J34.2, J34.3, J34.4, J49.6, J52.4; also elsewhere on the board
XB_CTS: J49.3; also elsewhere on the board
XB_RTS: J49.5; also elsewhere on the board
XB_RX: J49.2; also elsewhere on the board
XB_TX: J49.4; also elsewhere on the board

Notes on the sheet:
Additional IO peripherals
Additional Serial peripherals
IO expander peripherals (hall effect sensors)
Female Header Pins for Debug

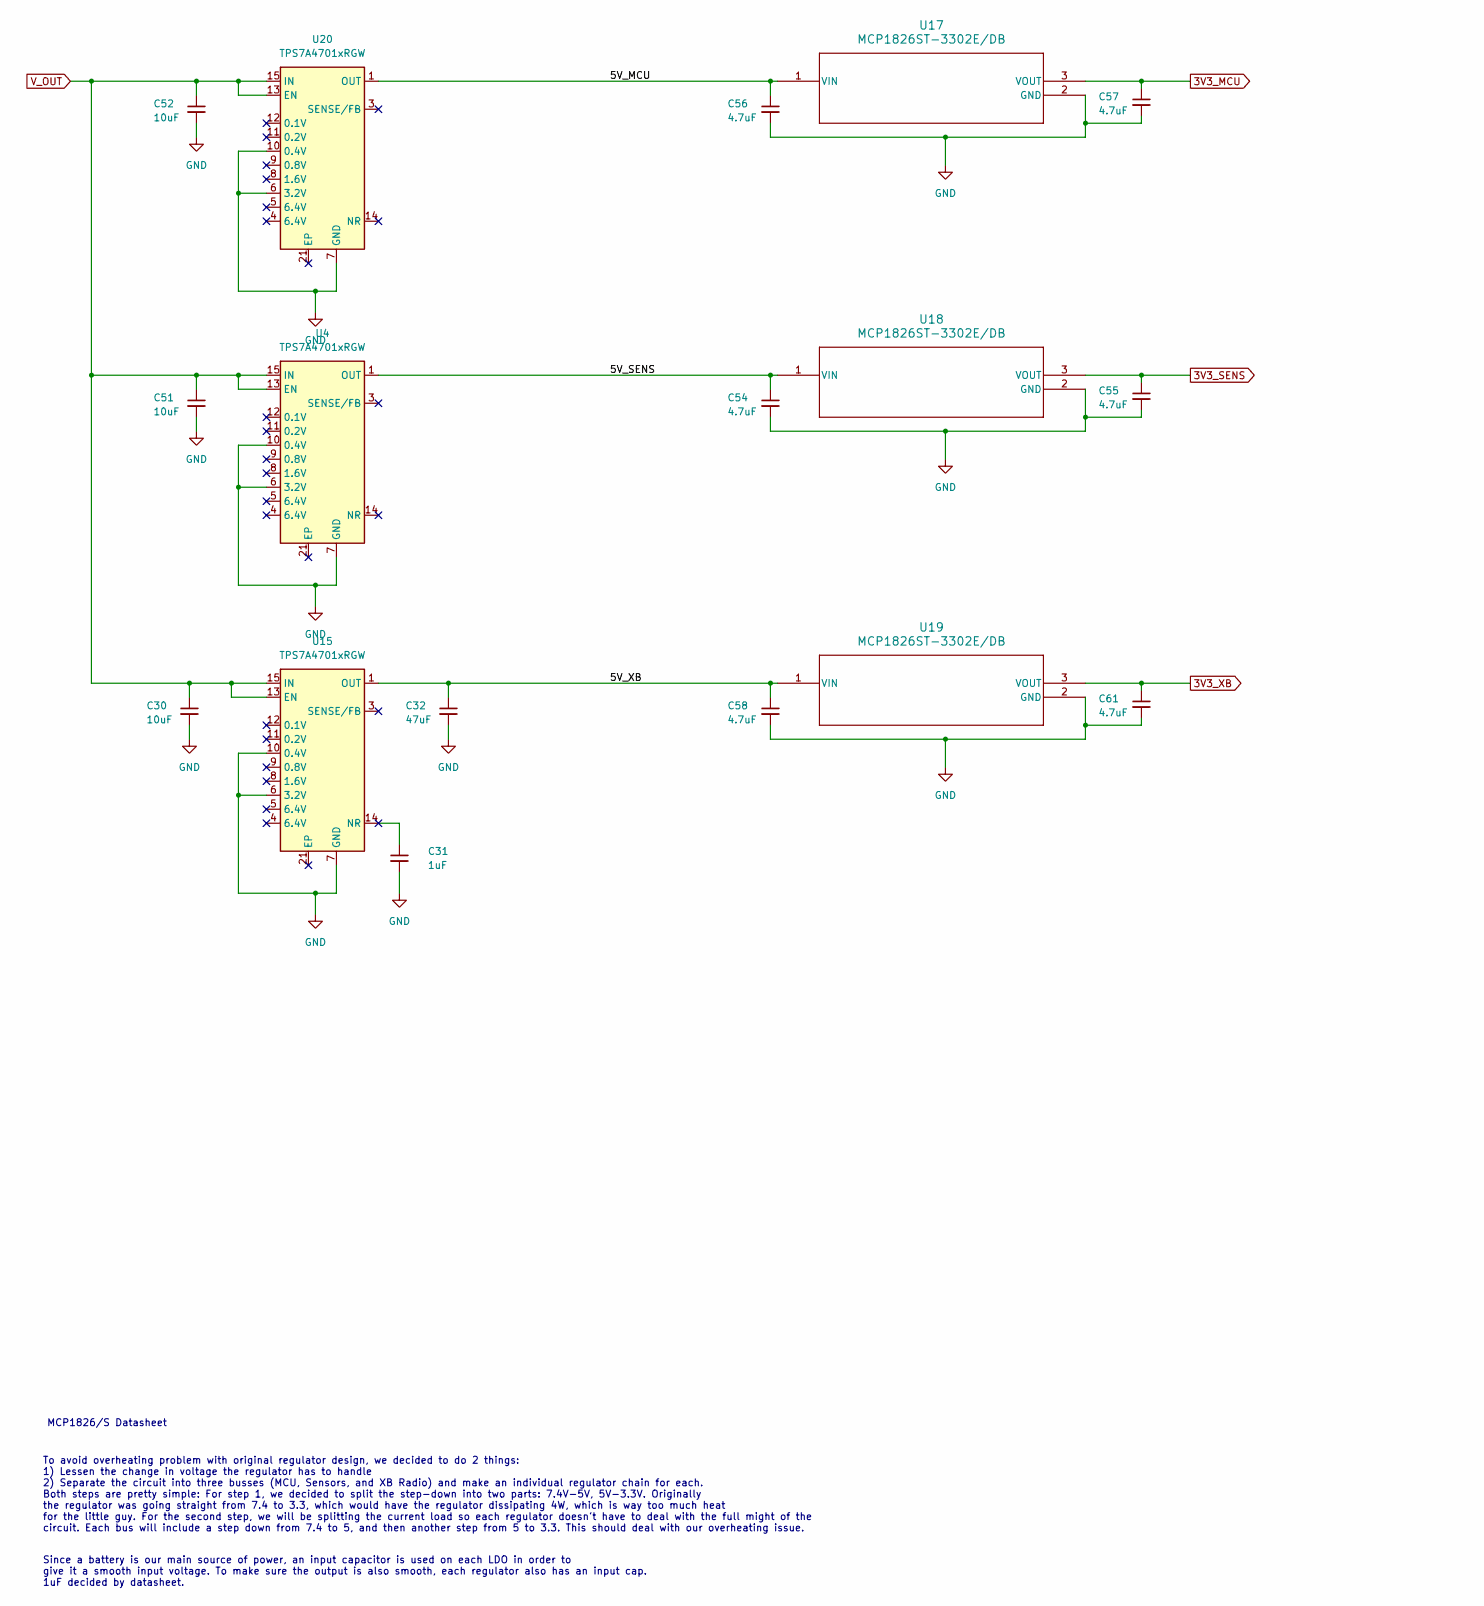
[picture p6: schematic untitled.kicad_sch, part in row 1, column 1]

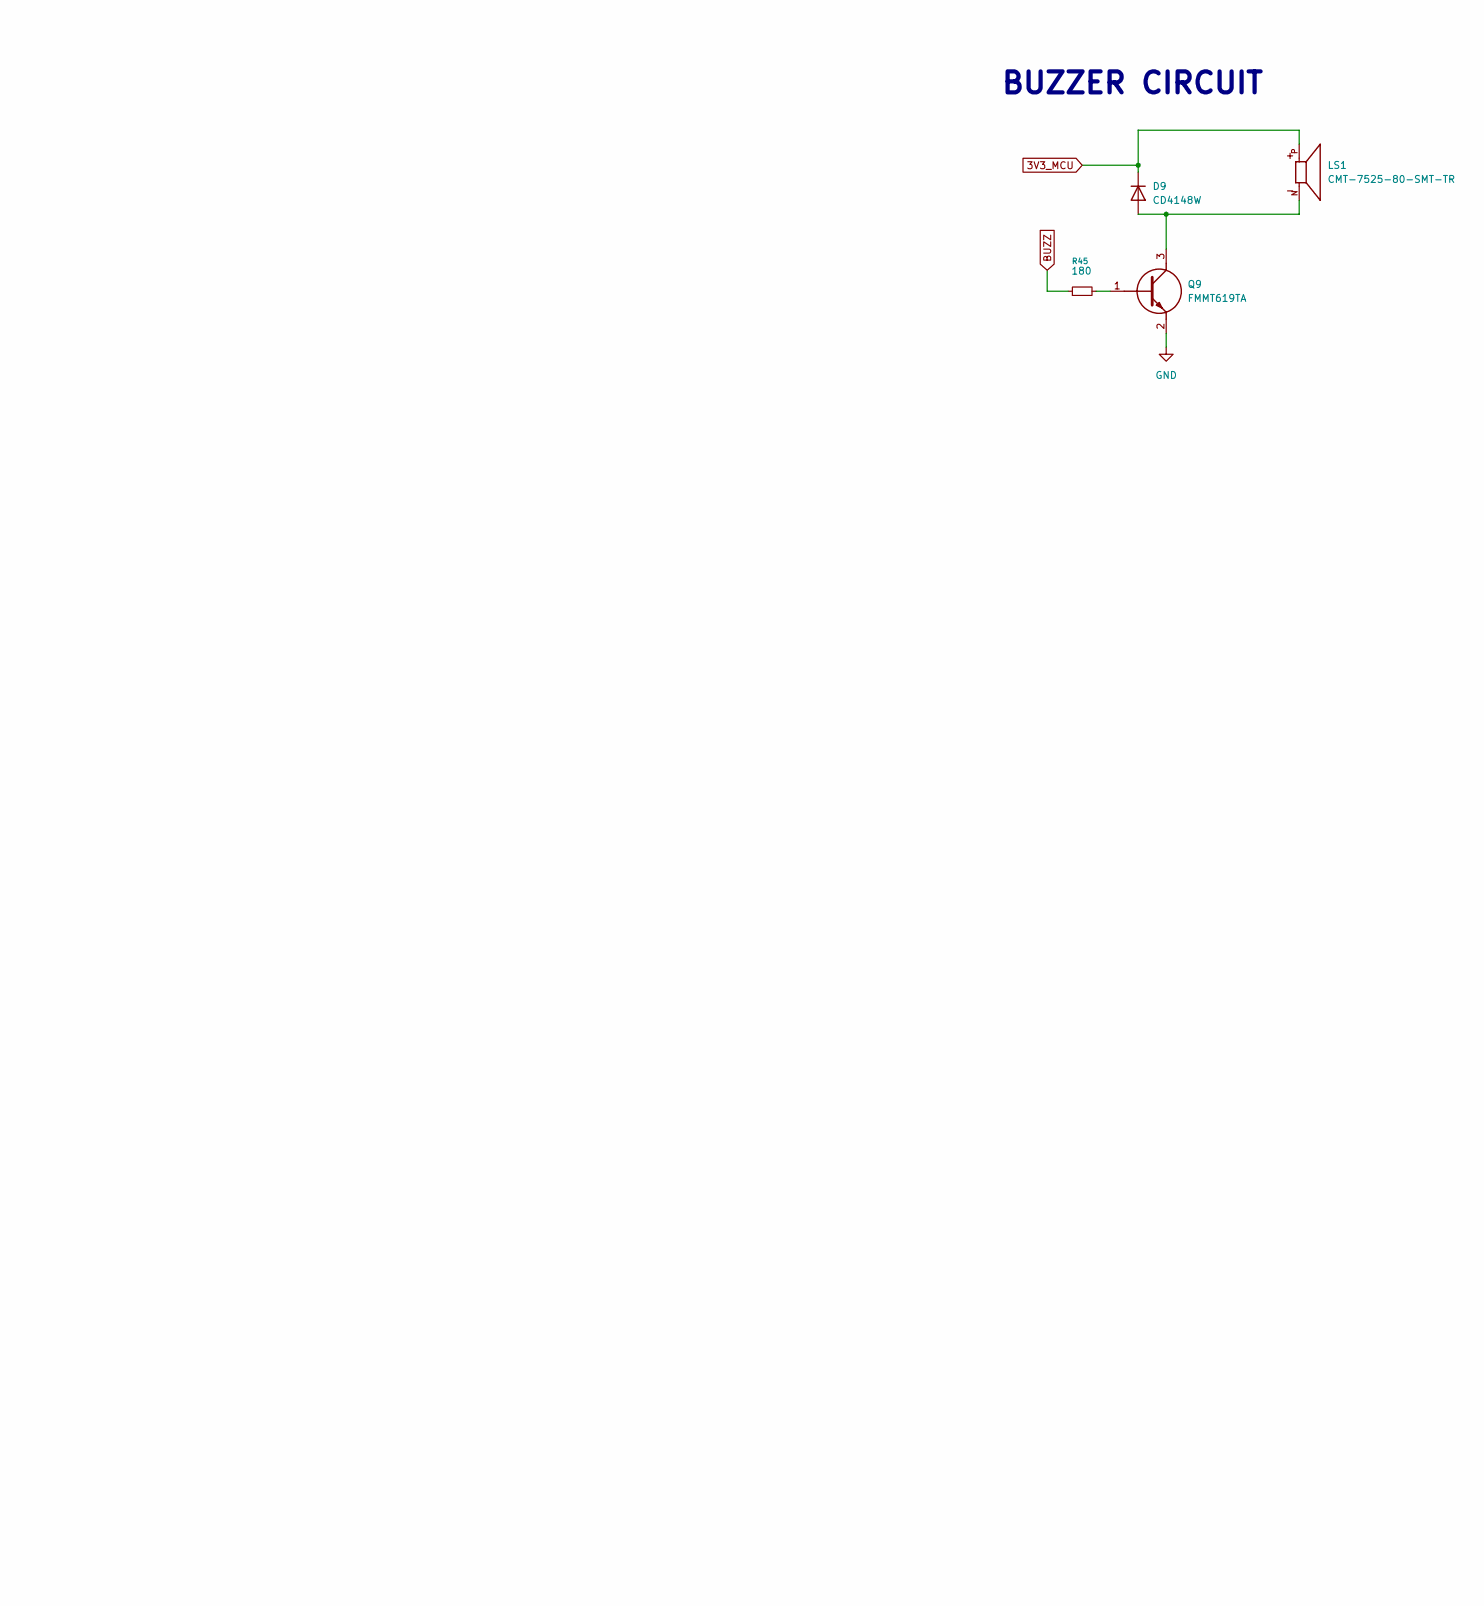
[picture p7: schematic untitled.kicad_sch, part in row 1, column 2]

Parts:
C30, C51, C52: 10uF; C_0805_2012Metric
C31: 1uF; C_0805_2012Metric
C32: 47uF; C_0805_2012Metric
C54, C55, C56, C57, C58, C61: 4.7uF; C_0805_2012Metric
D9: CD4148W; D_0805_2012Metric
LS1: CMT-7525-80-SMT-TR; XDCR_CMT-7525-80-SMT-TR; PARTREV N/A
Q9: FMMT619TA; SOT95P237X112-3N; Mouser Part Number 522-FMMT619TA
R45: 180; R_0805_2012Metric
U4, U15, U20: TPS7A4701xRGW; Texas_RGW0020A_VQFN-20-1EP_5x5mm_P0.65mm_EP3.15x3.15mm
U17, U18, U19: MCP1826ST-3302E/DB; SOT-223_3MC_MCH-L

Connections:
3V3_MCU: C57.1, D9.1 (K), LS1.P, U17.3 (VOUT); also elsewhere on the board
3V3_SENS: C55.1, U18.3 (VOUT); also elsewhere on the board
3V3_XB: C61.1, U19.3 (VOUT); also elsewhere on the board
/Chips/Regulators/5V_MCU: C56.1, U17.1 (VIN), U20.1 (OUT), U20.20 (OUT)
/Chips/Regulators/5V_SENS: C54.1, U4.1 (OUT), U4.20 (OUT), U18.1 (VIN)
/Chips/Regulators/5V_XB: C32.1, C58.1, U15.1 (OUT), U15.20 (OUT), U19.1 (VIN)
BUZZ: R45.1; also elsewhere on the board
unnamed: D9.2 (A), LS1.N, Q9.3 (C)
unnamed: Q9.1 (B), R45.2
VDDSMPS: C30.2, C31.2, C32.2, C51.2, C52.2, C54.2, C55.2, C56.2, C57.2, C58.2, C61.2, Q9.2 (E), U4.6 (3.2V), U4.7 (GND), U4.10 (0.4V), U15.6 (3.2V), U15.7 (GND), U15.10 (0.4V), U17.2 (GND), U18.2 (GND), U19.2 (GND), U20.6 (3.2V), U20.7 (GND), U20.10 (0.4V); also elsewhere on the board
V_OUT: C30.1, C51.1, C52.1, U4.13 (EN), U4.15 (IN), U4.16 (IN), U15.13 (EN), U15.15 (IN), U15.16 (IN), U20.13 (EN), U20.15 (IN), U20.16 (IN); also elsewhere on the board

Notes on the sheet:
MCP1826/S Datasheet
BUZZER CIRCUIT
To avoid overheating problem with original regulator design, we decided to do 2 things: 1) Lessen the change in voltage the regulator has to handle 2) Separate the circuit into three busses (MCU, Sensors, and XB Radio) and make an individual regulator chain for each. Both steps are pretty simple: F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
Since a battery is our main source of power, an input capacitor is used on each LDO in order to give it a smooth input voltage. To make sure the output is also smooth, each regulator also has an input cap. 1uF decided by datasheet.

Board: 2 copper layers, 129 parts (0 on the bottom side), 133 nets, no tracks yet.

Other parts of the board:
J2: Screw_Terminal_01x04; PHOENIX_1984633

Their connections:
SPI5_CLK: J2.1; also elsewhere on the board
SPI5_CS: J2.4; also elsewhere on the board
SPI5_MISO: J2.2; also elsewhere on the board
SPI5_MOSI: J2.3; also elsewhere on the board

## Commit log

2025-09-04 hooked VDD pins to power, includes decoupling and bulk capacitors
    [Aurora.kicad_sch]
2025-09-08 finished power pins
2025-09-08 fixed capacitors
    [Aurora.kicad_sch]
2025-09-08 hooked up USB receptacle, added ESD protection
    [Aurora.kicad_sch]
2025-09-10 updates to USB connection
    [Aurora.kicad_sch]
2025-09-13 Voltage regulator, some comments
    [Aurora.kicad_sch]
2025-09-13 added 7.4->5v regulator for battery
    [Aurora.kicad_sch]
2025-09-13 power multiplexer
    [Aurora.kicad_sch]
2025-09-13 ICM and other sensors
    [Aurora.kicad_sch]
2025-09-13 3.3v regulator
    [Aurora.kicad_sch]
2025-09-13 changed position of components on schm
    [Aurora.kicad_sch]
2025-09-13 Add KiCad auto merge workflow
2025-09-13 Implement 3-way KiCad-aware auto-merge script
    This script implements a 3-way auto-merge for KiCad files, handling conflicts based on specified rules for different object types and merging strategies.
2025-09-13 Add 3-way auto-merge script for KiCad files
    This script provides a 3-way auto-merge functionality for KiCad files, handling conflicts based on specified rules for different object types.
2025-09-13 Add KiCad auto-merge GitHub Actions workflow
2025-09-13 Add workflow_dispatch to KiCad auto merge workflow
2025-09-15 worked on figuring out VDD12DSI pins and VDDSMPS pins, hopefully this is correct
    [Aurora.kicad_sch]
2025-09-16 changes to capacitors, LDO, SMPS stuff
    [Aurora.kicad_sch]
2025-09-16 Revert "merging conflicts"
    This reverts commit 3d8ae35df3231aee76086947d4fef95e6f82343e, reversing
    changes made to c2fa33c742d47faaac57159af77864f609f31e02.
    [Aurora.kicad_sch]
2025-09-18 began wiring up sensors
    [Aurora.kicad_sch]
2025-09-23 did some work on gyroscope, wired up IMU
    [Aurora.kicad_sch]
2025-09-23 began wiring ICM-45686 and BNO085 to chip
2025-09-24 wired up ICM-45686, ICM-42688, and Barometer to STM
    [Aurora.kicad_sch]
2025-10-14 SD Card wired up
    [Aurora.kicad_sch]
2025-10-16 Hooked up XB radio, began breaking out the rest of the SPI and UART pins
    [Aurora.kicad_sch]
2025-11-17 lots of changes; sensors, LEDs, screw terminal blocks
    [Aurora.kicad_pcb, Aurora.kicad_sch, Chips.kicad_sch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]
2025-11-18 3rd ADC
    [top.kicad_sch]
2025-11-18 Boot0 and NRST pins
    [Chips.kicad_sch]
2025-12-01 All CS pins include 10k pullups on SPI buses
    [Chips.kicad_sch]
2025-12-02 some changes to the reset and boot pins, wip
    [Chips.kicad_sch]
2026-01-05 new baro
    [Aurora.kicad_pcb, Aurora.kicad_sch, Chips.kicad_sch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]
2026-01-05 PU resistor on CS for baro
    [Chips.kicad_sch]
2026-01-09 added new regulator chain + rationale
    [Aurora.kicad_sch, Chips.kicad_sch, untitled.kicad_sch]
2026-01-14 regulators mount up
    [pyros.kicad_sch, untitled.kicad_sch]
2026-01-22 bom updates (purchase links, prices, etc) and switching imu because out of stock
    [Chips.kicad_sch, pyros.kicad_sch, top.kicad_sch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]
2026-01-22 undo imu switch grant got scammed
    [Chips.kicad_sch]
2026-01-26 added pyros, voltage booster
    [Aurora.kicad_sch, Chips.kicad_sch, pyros.kicad_sch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]
2026-01-29 working though GPIOs/CSs, Xref with cubeMX
    [Chips.kicad_sch, pyros.kicad_sch, top.kicad_sch]
2026-01-30 continued updating gpios and interrupt pins
    [Chips.kicad_sch, untitled.kicad_sch]
2026-02-03 BNO/baro pins, pullups added to all active low pins on Baro
    [Chips.kicad_sch]
2026-02-03 pullup on BNO CS
    [Chips.kicad_sch]
2026-02-05 done with debug header pins
    [Chips.kicad_sch, pyros.kicad_sch]
2026-02-06 added breakouts for xb and stlink
    [Chips.kicad_sch]
2026-02-12 fixed header pins, XB on UART
    [Chips.kicad_sch, pyros.kicad_sch]
2026-02-12 NOW the xb is on UART
    [Chips.kicad_sch]
2026-02-17 changes to net labelling
    [Chips.kicad_sch, pyros.kicad_sch, top.kicad_sch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]
2026-02-25 fixed schematic issues, started organizing components in PCB
    [Aurora.kicad_pcb, Aurora.kicad_sch, Chips.kicad_sch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]
2026-03-06 layout and changed screw term size
    [Aurora.kicad_pcb, pyros.kicad_sch]
2026-03-18 changing a lot of stuff, like components and footprints
    [Middle.kicad_pcb, Middle.kicad_sch, TopBoard.kicad_pcb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]
